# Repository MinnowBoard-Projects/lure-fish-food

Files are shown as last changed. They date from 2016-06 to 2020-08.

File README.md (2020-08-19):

# Fish Food Lure for MinnowBoard SBC.

**Fish Food Lure** is a breadboard adapter for the MinnowBoard MAX / Turbot single boards computers (because you feed bread to fish).   
This lure enables fast prototyping on a breadboard, connects to the MinnowBoard using a ribbon cable.      

Lure naming credit goes to John Hawley aka [Warthog9](https://github.com/warthog9) 

You can purchase this lure with *[Netgate](https://store.netgate.com/Lures/FishFood.aspx)*.

> Released under the Creative Commons Attribution 3.0 License     
> https://creativecommons.org/licenses/by/3.0/   
> Designed using DipTrace 3.0

## KiCad version added to this repository. 

> Released under the Creative Commons Attribution 3.0 License     
> https://creativecommons.org/licenses/by/3.0/   
> Designed using KiCad 4.0.7
> Located in this directory: Fish_Food_Lure_KiCad

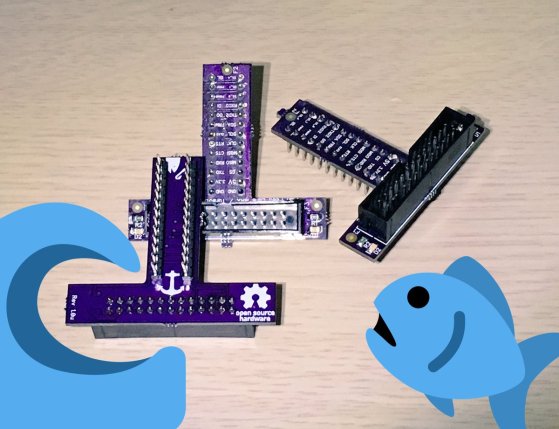
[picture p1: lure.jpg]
Fish Food Lure


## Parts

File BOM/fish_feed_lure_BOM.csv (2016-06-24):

RefDes | Value | Name | Manufacturer part | Manufacturer | Quantity | Link | Replacement
26pin | 929834-01-13 | 13 position pin strip | 929834-01-13 | 3M Electronic Solutions Division | 2 | http://www.mouser.com/ProductDetail/3M/929834-01-13/?qs=FRjC07T2dBSSXUzZuwV4UQ%3d%3d | http://www.mouser.com/ProductDetail/Wurth-Electronics/61301311121/
D1 | Green LED | DIODE_0805 | SML-LXT0805GW-TRLumex |  | 1 | http://www.mouser.com/Search/ProductDetail.aspx
D2 | Red LED | DIODE_0805 | SML-LXT0805IW-TR | Lumex | 1 | http://www.mouser.com/Search/ProductDetail.aspx
R1 | 180 ohms | RES_0805 ERJ-6GEYJ181V | ERJ-6GEYJ181V | Panasonic | 1 | http://www.mouser.com/Search/ProductDetail.aspx
R2 | 68 ohms | RES_0805 SG73S2ATTD680J | SG73S2ATTD680J | KOA Speer | 1 | http://www.mouser.com/Search/ProductDetail.aspx
ShroudedHeader | 61202621621 | Shrouded MAX / Turbot Compatible LSE | 61202621621 | Wurth Electronics | 1 | http://www.mouser.com/Search/ProductDetail.aspx

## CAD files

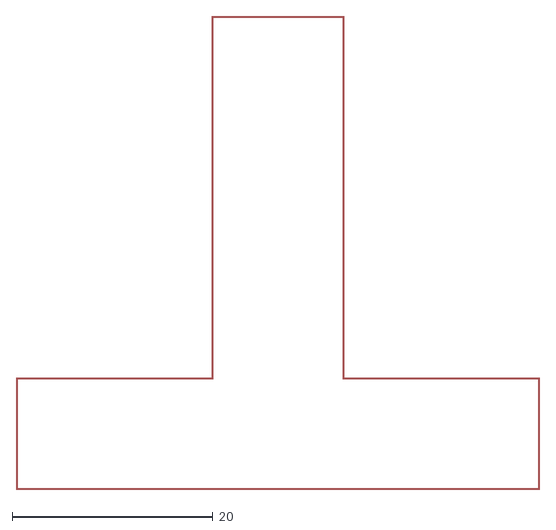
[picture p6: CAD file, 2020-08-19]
Fish_Food_Lure_KiCad/fish_food_lure_dxf.dxf
52.2 x 47.2

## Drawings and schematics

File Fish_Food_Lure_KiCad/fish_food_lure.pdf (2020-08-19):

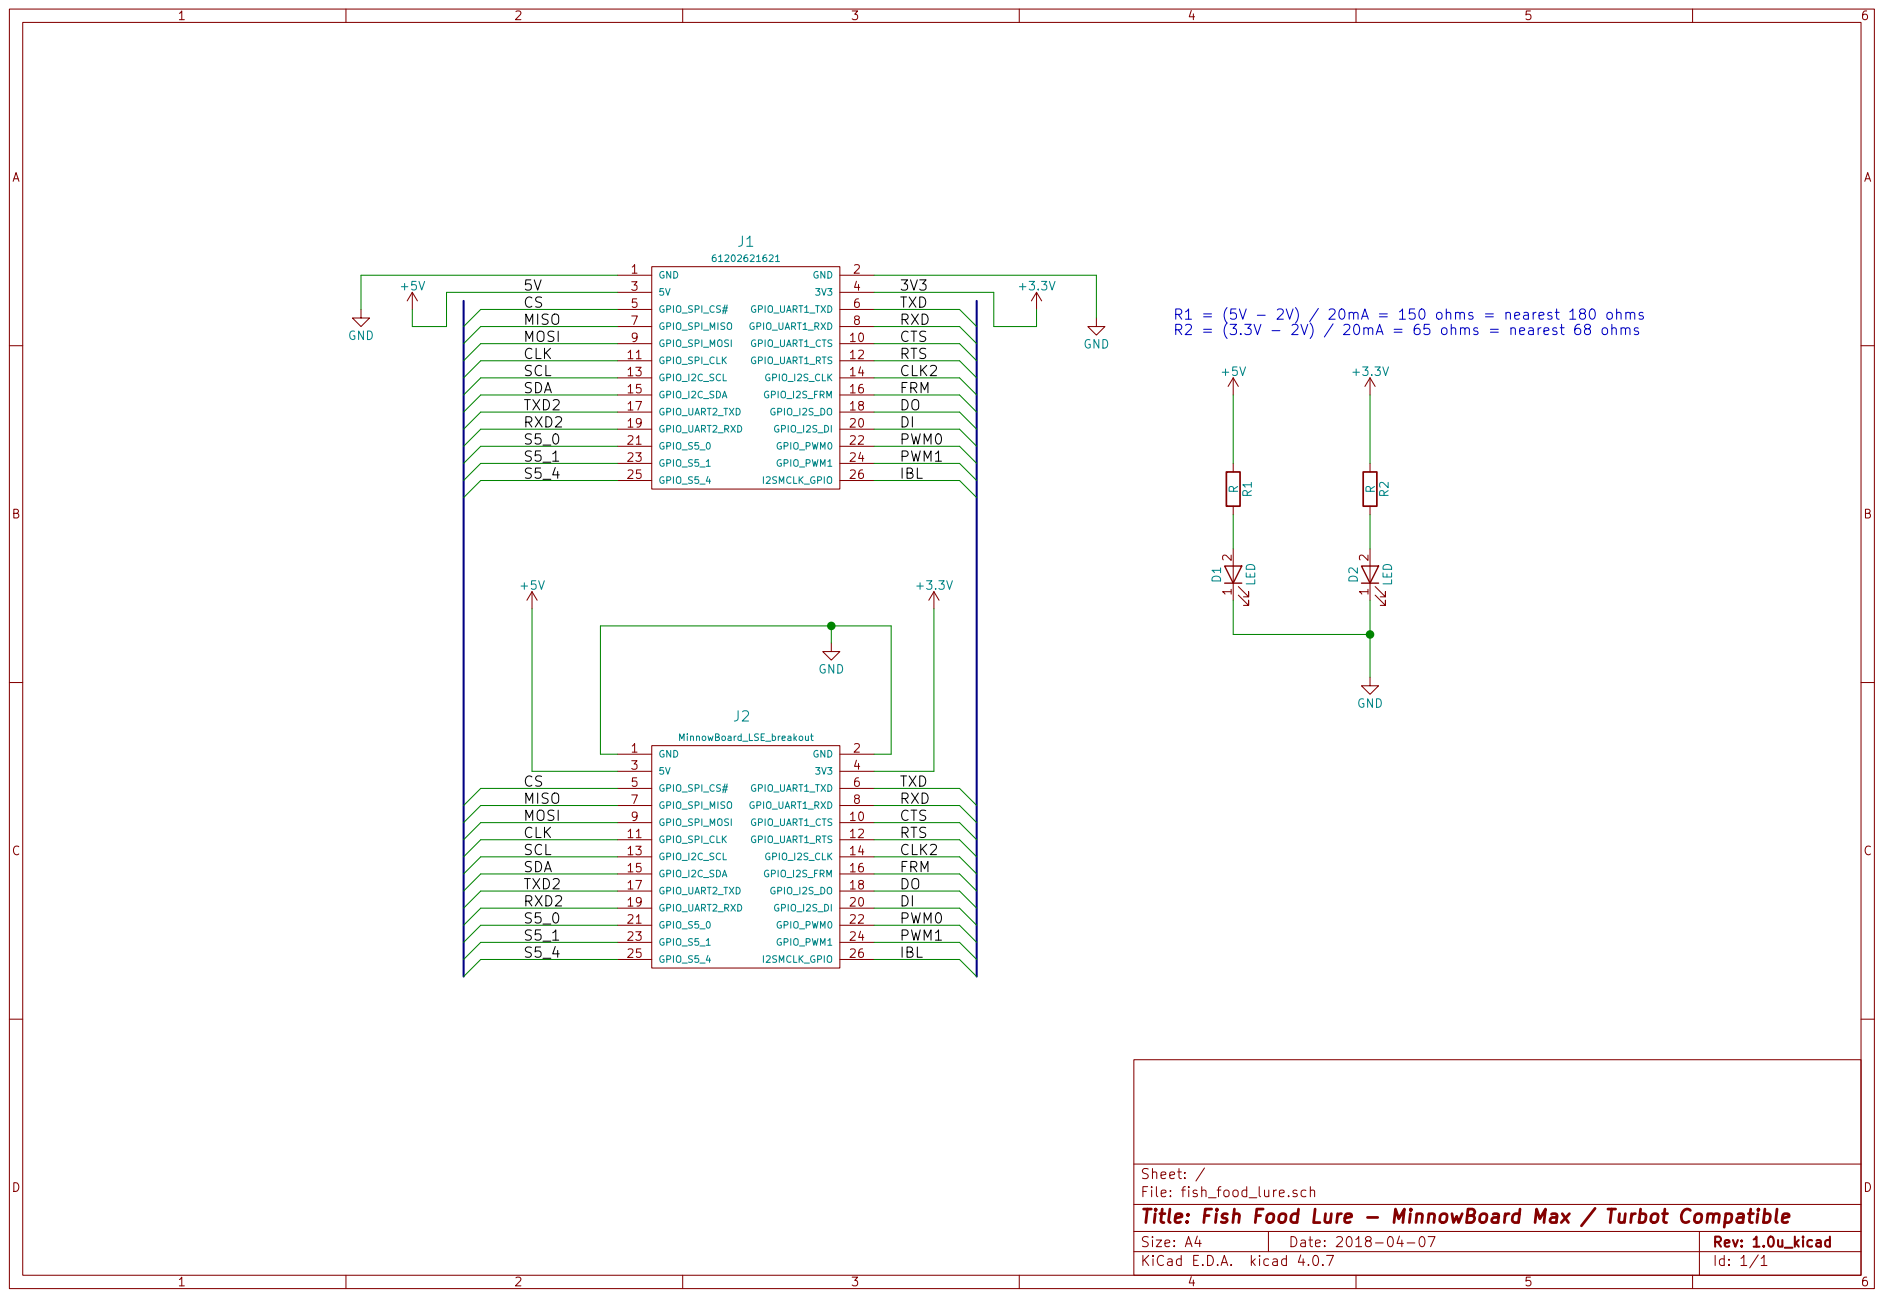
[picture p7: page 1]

File: fish_food_lure.sch Sheet: /
Id: 1/1 Title: Fish Food Lure - MinnowBoard Max / Turbot Compatible

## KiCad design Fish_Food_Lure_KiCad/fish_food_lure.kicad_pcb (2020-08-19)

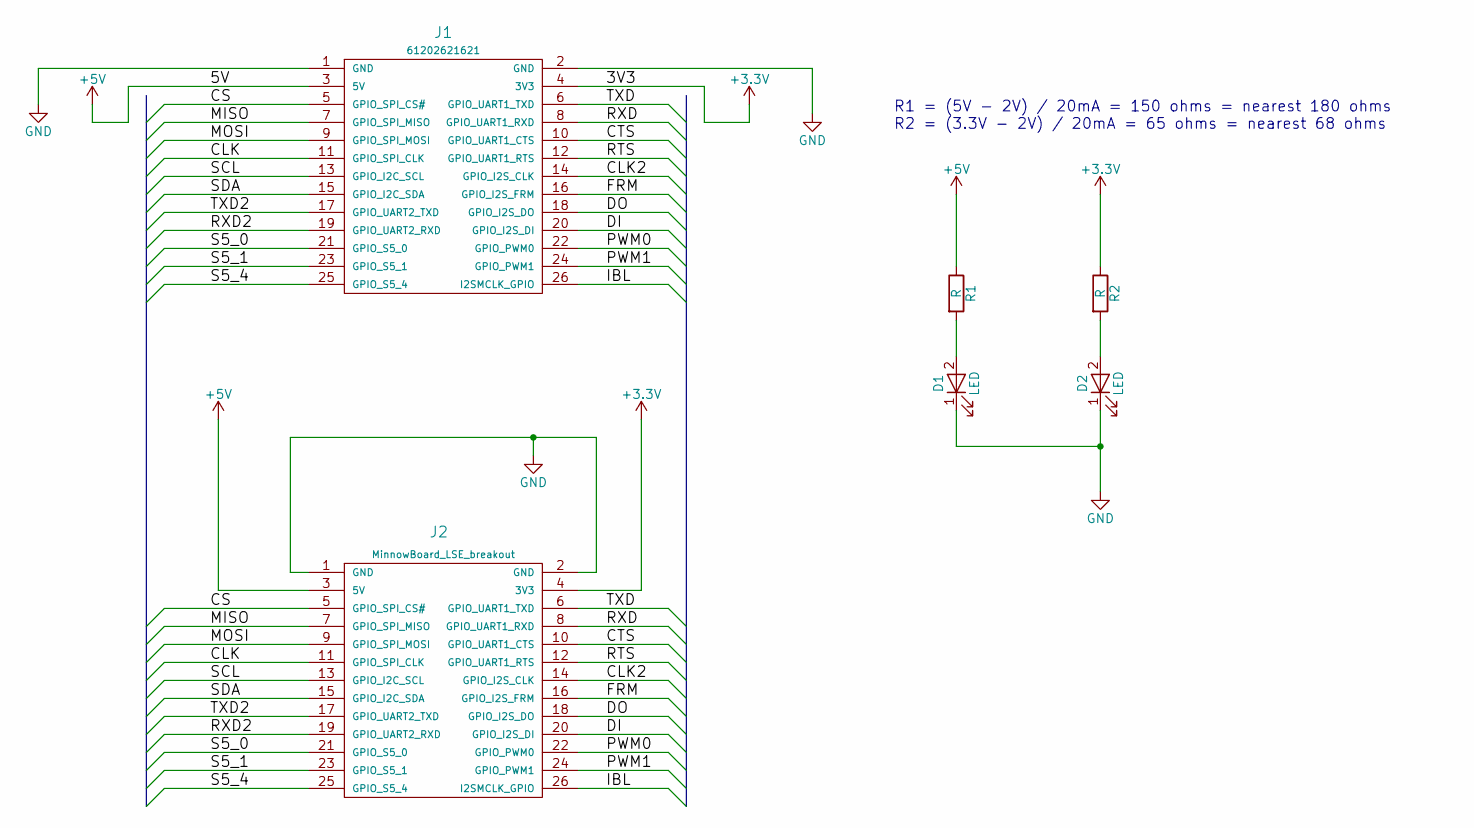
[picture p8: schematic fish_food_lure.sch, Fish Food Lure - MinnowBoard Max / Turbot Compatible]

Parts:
D1, D2: LED; LED_0805
J1: 61202621621
J2: MinnowBoard_LSE_breakout; 26_pin_breadboard
R1, R2: R; R_0805

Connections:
+3V3: J1.4 (3V3), J2.4 (3V3), R2.1
+5V: J1.3 (5V), J2.3 (5V), R1.1
/CLK: J1.11 (GPIO_SPI_CLK), J2.11 (GPIO_SPI_CLK)
/CLK2: J1.14 (GPIO_I2S_CLK), J2.14 (GPIO_I2S_CLK)
/CS: J1.5 (GPIO_SPI_CS#), J2.5 (GPIO_SPI_CS#)
/CTS: J1.10 (GPIO_UART1_CTS), J2.10 (GPIO_UART1_CTS)
/DI: J1.20 (GPIO_I2S_DI), J2.20 (GPIO_I2S_DI)
/DO: J1.18 (GPIO_I2S_DO), J2.18 (GPIO_I2S_DO)
/FRM: J1.16 (GPIO_I2S_FRM), J2.16 (GPIO_I2S_FRM)
/IBL: J1.26 (I2SMCLK_GPIO), J2.26 (I2SMCLK_GPIO)
/MISO: J1.7 (GPIO_SPI_MISO), J2.7 (GPIO_SPI_MISO)
/MOSI: J1.9 (GPIO_SPI_MOSI), J2.9 (GPIO_SPI_MOSI)
/PWM0: J1.22 (GPIO_PWM0), J2.22 (GPIO_PWM0)
/PWM1: J1.24 (GPIO_PWM1), J2.24 (GPIO_PWM1)
/RTS: J1.12 (GPIO_UART1_RTS), J2.12 (GPIO_UART1_RTS)
/RXD: J1.8 (GPIO_UART1_RXD), J2.8 (GPIO_UART1_RXD)
/RXD2: J1.19 (GPIO_UART2_RXD), J2.19 (GPIO_UART2_RXD)
/S5_0: J1.21 (GPIO_S5_0), J2.21 (GPIO_S5_0)
/S5_1: J1.23 (GPIO_S5_1), J2.23 (GPIO_S5_1)
/S5_4: J1.25 (GPIO_S5_4), J2.25 (GPIO_S5_4)
/SCL: J1.13 (GPIO_I2C_SCL), J2.13 (GPIO_I2C_SCL)
/SDA: J1.15 (GPIO_I2C_SDA), J2.15 (GPIO_I2C_SDA)
/TXD: J1.6 (GPIO_UART1_TXD), J2.6 (GPIO_UART1_TXD)
/TXD2: J1.17 (GPIO_UART2_TXD), J2.17 (GPIO_UART2_TXD)
GND: D1.1 (K), D2.1 (K), J1.1 (GND), J1.2 (GND), J2.1 (GND), J2.2 (GND)
unnamed: D1.2 (A), R1.2
unnamed: D2.2 (A), R2.2

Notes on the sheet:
R1 = (5V - 2V) / 20mA = 150 ohms = nearest 180 ohms R2 = (3.3V - 2V) / 20mA = 65 ohms = nearest 68 ohms

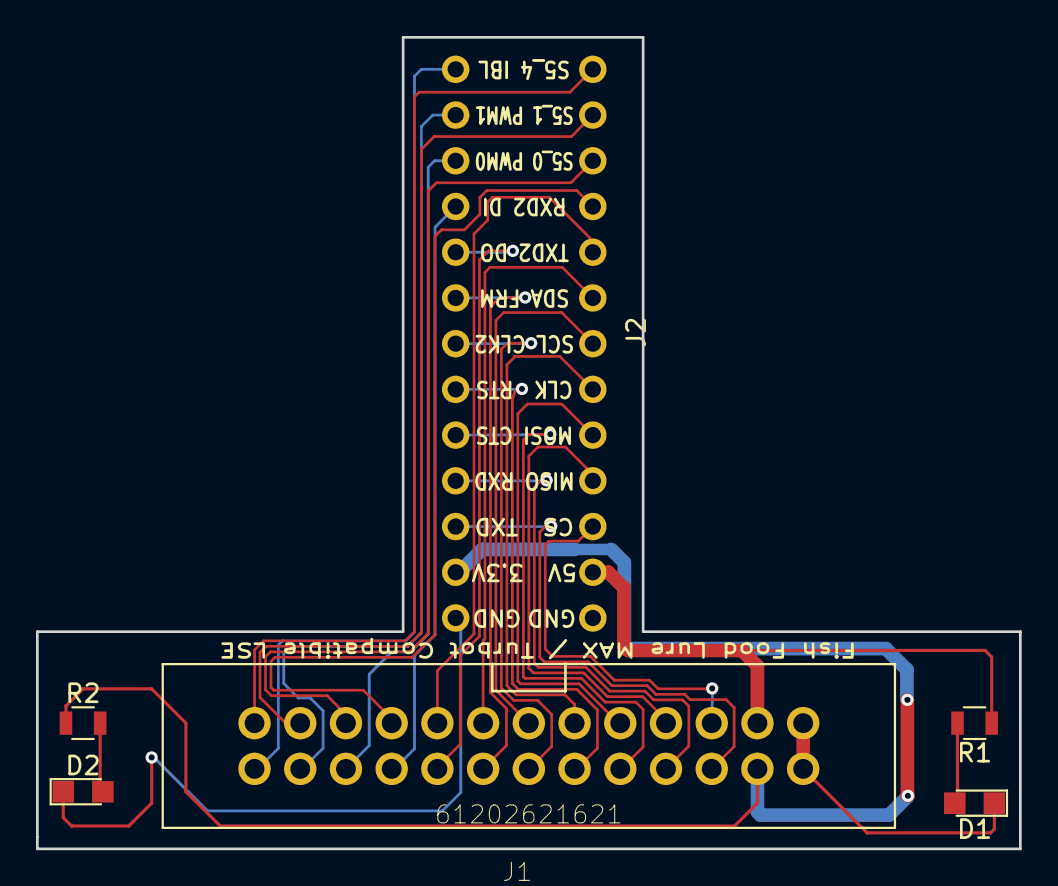
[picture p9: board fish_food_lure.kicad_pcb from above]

Board: 2 copper layers, 54.6 x 45.1 mm, 6 parts (0 on the bottom side), 27 nets.

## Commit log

2016-06-23 Initial commit
    Initial commit of the Fish Food Lure.
    [Board.gbr, BoardOutline.gbr, Bottom.gbr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]
2016-06-23 Moved schematic
    Moved schematic
2016-06-24 BOM update
    Updated BOM with current replacement for the 13 pin header.
    [fish_feed_lure_BOM.csv]
2016-08-19 Silkscreen Fix
    Silkscreen fix and gerber files refresh.
    [Board.gbr, BoardOutline.gbr, Bottom.gbr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]
2017-06-10 Typo fix on schematic file and PDF schematic
    Typo fix on schematic file and PDF schematic, changed from Fish Feed
    Lure to Fish Food Lure.
2020-08-19 Added KiCad port
    Added the KiCad port of the Fish Food Lure
